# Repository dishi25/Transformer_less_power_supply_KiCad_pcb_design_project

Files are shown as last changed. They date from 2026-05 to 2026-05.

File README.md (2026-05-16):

# Transformer-less Power Supply pcb_design (KiCad Project)

## Overview
This project demonstrates the design of a **transformer-less power supply** using KiCad.  
The circuit converts AC mains input into a regulated DC output using capacitive voltage dropping, rectification, filtering, and regulation.  

---

### Key Components
| Component | Value/Part | Notes |
|---|---|---|
| R1, R2 | 20kΩ | Voltage divider |
| R3 | 1MΩ | Bleeder resistor |
| R4 | 2.2kΩ | LED current limit |
| C1 | 0.1µF | Filter capacitor |
| C2 | 1000µF | Bulk capacitor |
| C3 | 470µF | Output smoothing |
| D1–D4 | 1N4001 | Bridge rectifier |
| D5, D6 | Zener diodes | Voltage regulation |
| D7 | LED | Power indicator |
| U1 | LM7805 | 5V regulator |
| J1 | AC input terminal |
| J2 | DC output terminal |

---

## Software
- **EDA Tool:** KiCad 9.0.7  
- **Gerber Viewer:** KiCad Gerber Viewer (or any online Gerber viewer)  
- **Version Control:** Git + GitHub  

---

## Visuals

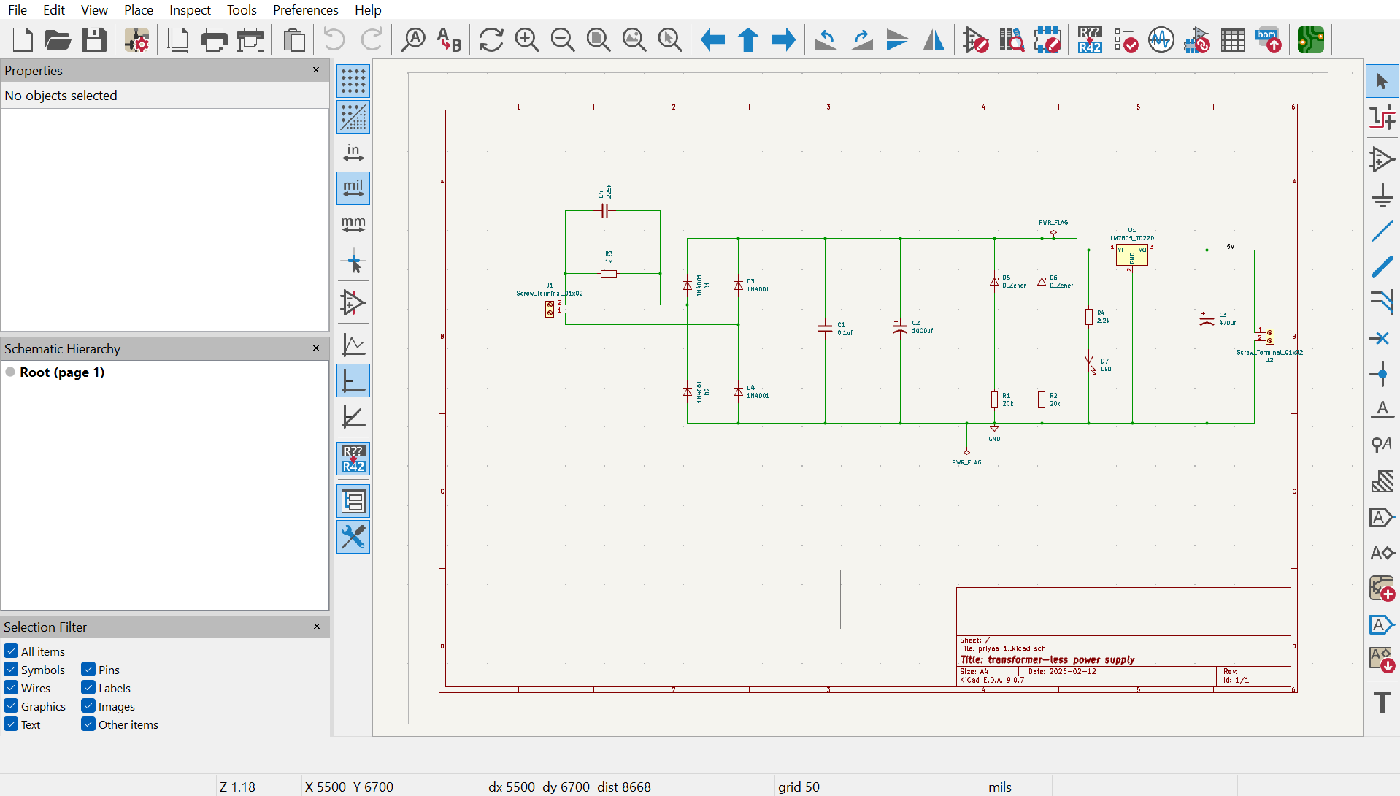
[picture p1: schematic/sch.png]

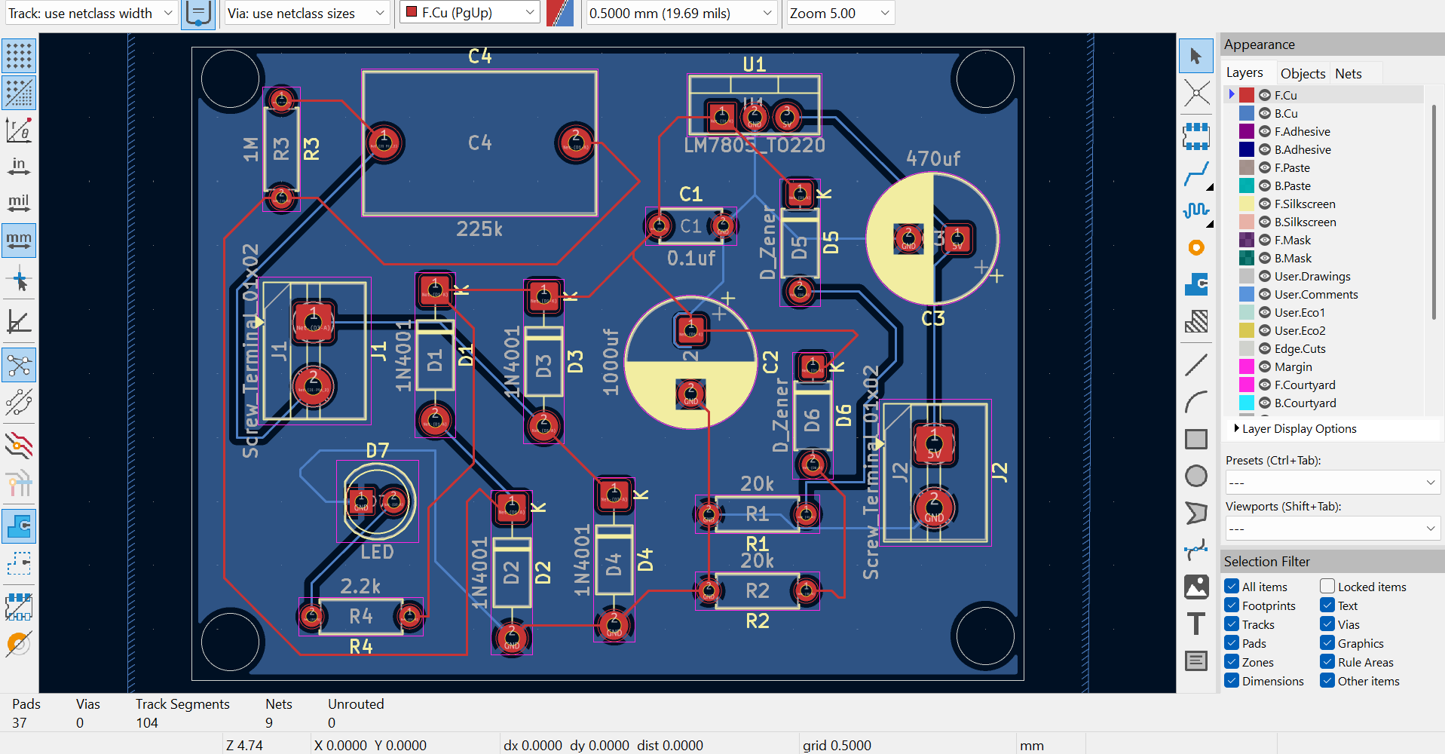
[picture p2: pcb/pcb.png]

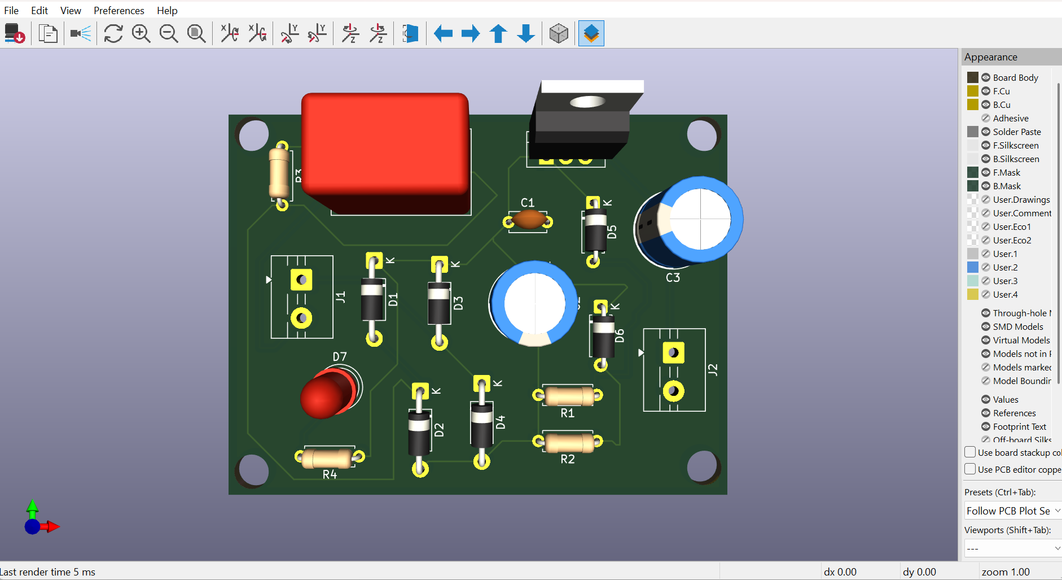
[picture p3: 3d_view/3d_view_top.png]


---

## Safety Disclaimer
This project involves **direct connection to mains AC**.  
It is intended for **educational and simulation purposes only**.  
Do not attempt to build or test without proper isolation, supervision, and protective equipment.  
Always follow electrical safety standards.

---
## Team:
V VAISHNAVI
GURUPRIYAA N
DISHIKA G

## Institution: Vellore Institute of Technology (VIT)

Support If you found this project inspiring, consider giving it a star on GitHub to support further development and encourage open-source innovation.

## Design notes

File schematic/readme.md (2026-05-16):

schematic code and images were uploaded here

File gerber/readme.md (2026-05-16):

gerber file .gbr and .drl files are attached here can be viewed by KiCad gerber viewer

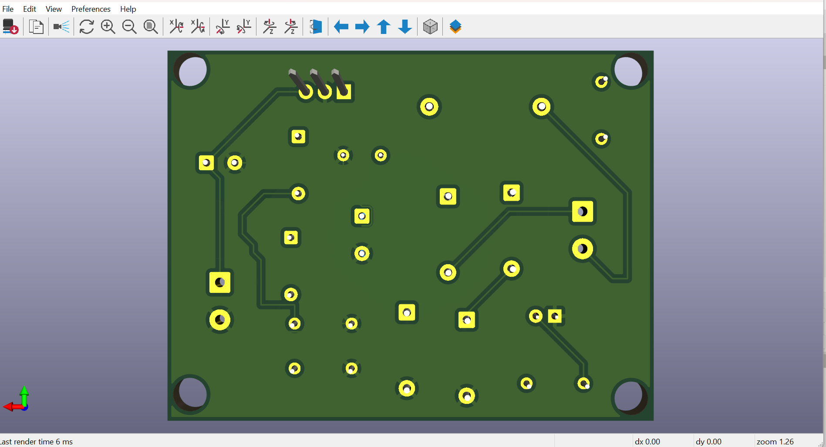
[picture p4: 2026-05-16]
3d_view/3d_view_back.png

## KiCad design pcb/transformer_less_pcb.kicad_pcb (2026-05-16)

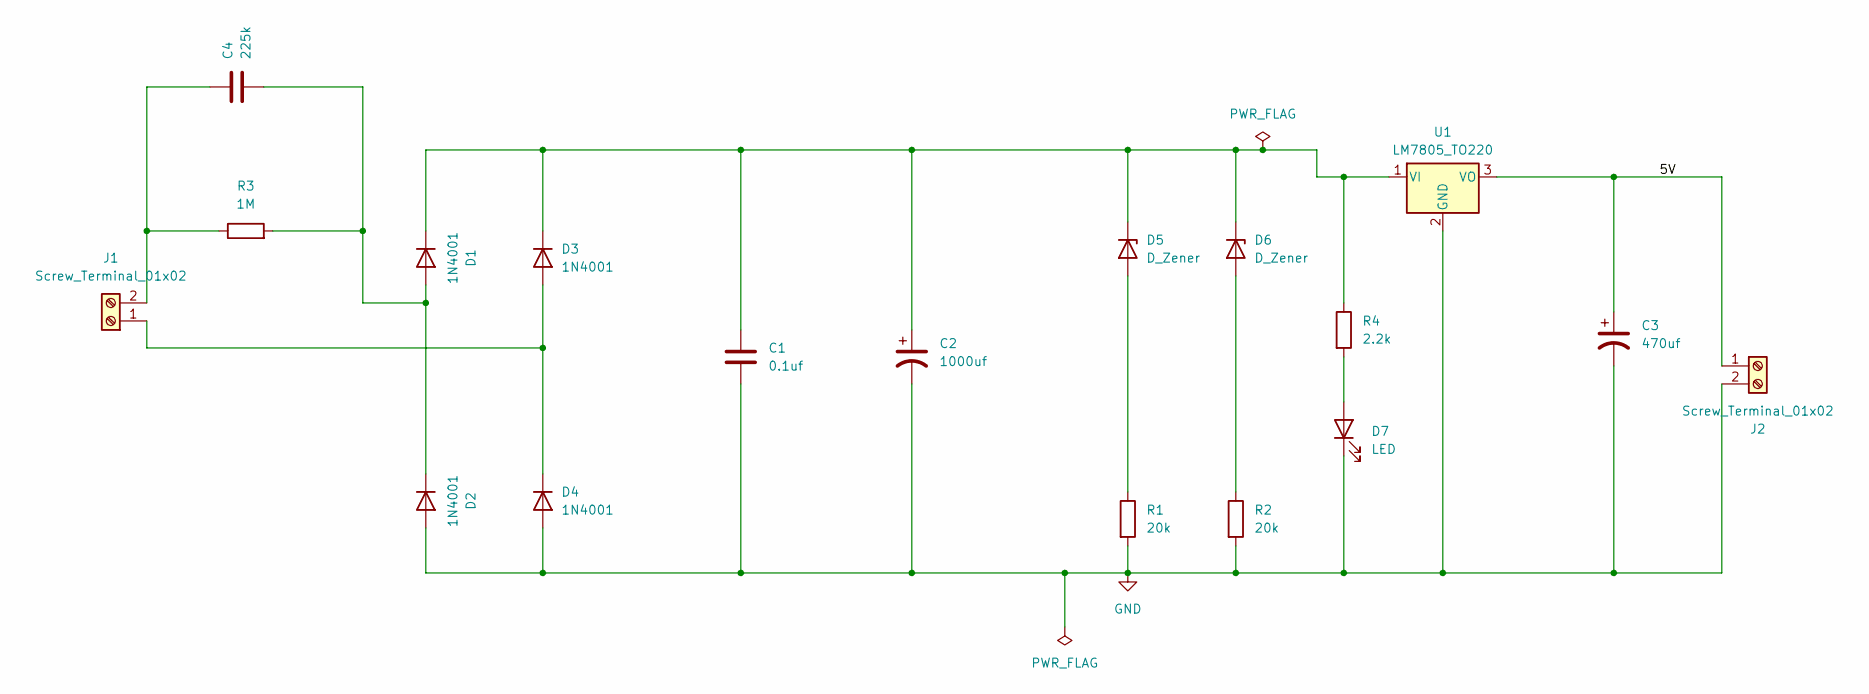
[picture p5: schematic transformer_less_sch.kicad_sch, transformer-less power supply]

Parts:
C1: 0.1uf; C_Disc_D4.7mm_W2.5mm_P5.00mm
C2: 1000uf; CP_Radial_D10.0mm_P5.00mm
C3: 470uf; CP_Radial_D10.0mm_P3.80mm
C4: 225k; C_Rect_L18.0mm_W11.0mm_P15.00mm_FKS3_FKP3
D1, D2, D3, D4: 1N4001; D_DO-41_SOD81_P10.16mm_Horizontal
D5, D6: D_Zener; D_A-405_P7.62mm_Horizontal
D7: LED; LED_D5.0mm
J1, J2: Screw_Terminal_01x02; TerminalBlock_MaiXu_MX126-5.0-02P_1x02_P5.00mm
R1, R2: 20k; R_Axial_DIN0207_L6.3mm_D2.5mm_P7.62mm_Horizontal
R3: 1M; R_Axial_DIN0207_L6.3mm_D2.5mm_P7.62mm_Horizontal
R4: 2.2k; R_Axial_DIN0207_L6.3mm_D2.5mm_P7.62mm_Horizontal
U1: LM7805_TO220; TO-220-3_Vertical

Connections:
/5V: C3.1, J2.1, U1.3 (VO)
GND: C1.2, C2.2, C3.2, D2.2 (A), D4.2 (A), D7.1 (K), J2.2, R1.2, R2.2, U1.2 (GND)
unnamed: C4.2, D1.2 (A), D2.1 (K), R3.2
unnamed: C1.1, C2.1, D1.1 (K), D3.1 (K), D5.1 (K), D6.1 (K), R4.1, U1.1 (VI)
unnamed: D3.2 (A), D4.1 (K), J1.1
unnamed: D5.2 (A), R1.1
unnamed: D6.2 (A), R2.1
unnamed: D7.2 (A), R4.2
unnamed: C4.1, J1.2, R3.1

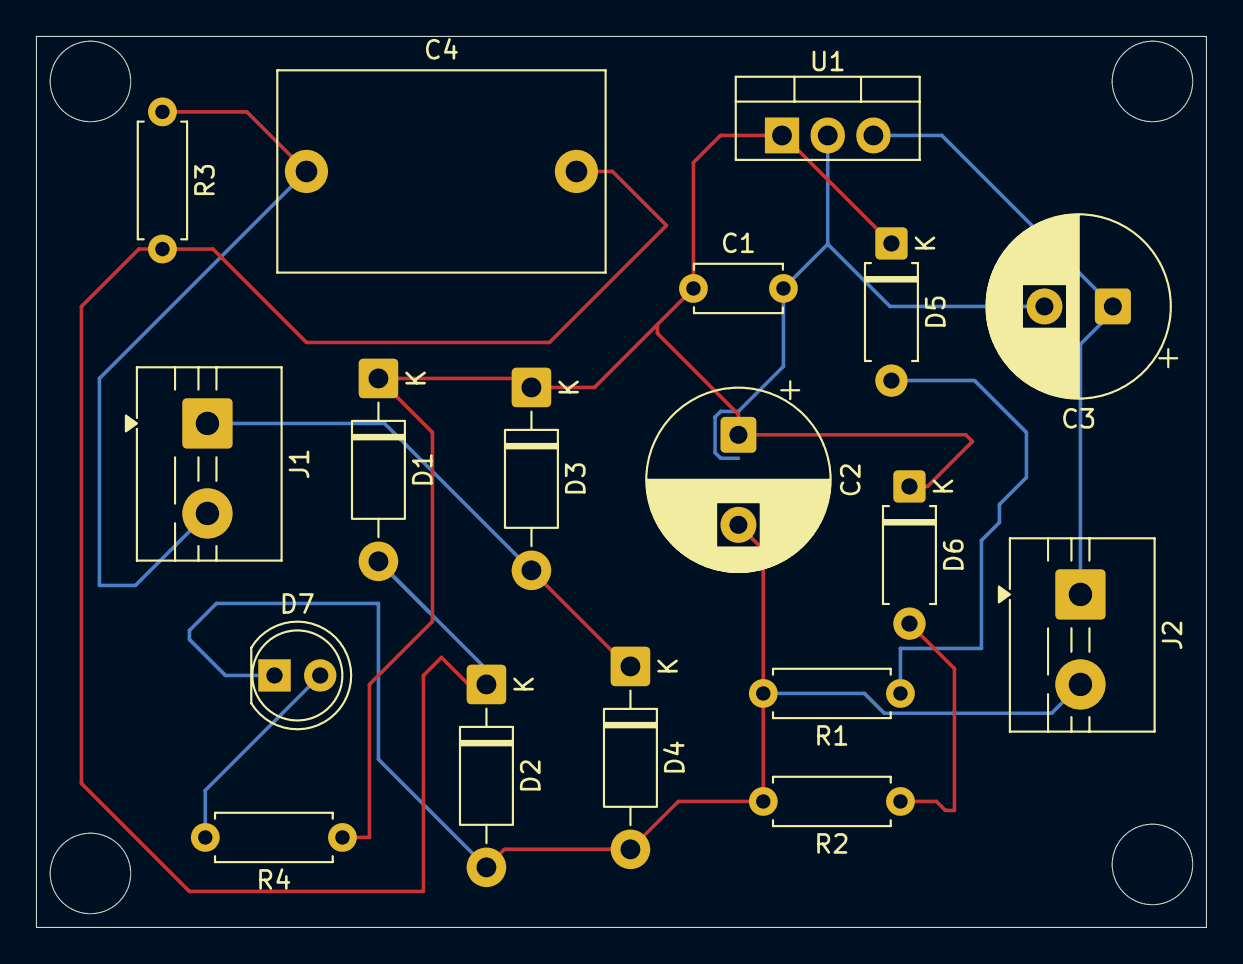
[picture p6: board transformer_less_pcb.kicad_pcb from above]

Board: 2 copper layers, 65.0 x 49.5 mm, 18 parts (0 on the bottom side), 9 nets.

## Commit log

2026-05-16 Update readme with gerber file information
    Add description for gerber files and KiCad viewer.
2026-05-16 Add description to schematic README
2026-05-16 Add Bill of Materials note to readme
